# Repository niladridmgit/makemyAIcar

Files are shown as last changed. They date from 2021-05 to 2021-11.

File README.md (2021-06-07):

# makemyAIcar V2

## Below components used:
1. <del>Raspberry Pi 4 (2GB)</del> due to performance issue decided to go with **Jetson nano 4GB - B01**
2. <del>Raspberry Pi 4 Aluminum Heat Sink Case with Double Fans  [LINK](https://www.amazon.in/REES52-Raspberry-Armor-Aluminium-Heatsink/dp/B07X5XXKTZ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)</del> this is not compatible with jetson nano so added **4 Sqcm 5v colling fan**
3. <del>32gb SanDisk Extreme</del> upgraded to **USB SSD 256 gb** 
5. Raspberry Pi Camera V2 and IMX219-77 8MP Camera with 77° FOV
6. Car Chassis Transparent 4Wd  [LINK](https://www.amazon.in/gp/product/B01MT9Z9QB/ref=ppx_yo_dt_b_asin_title_o01_s00?ie=UTF8&psc=1) 
7. <del>8Ybj-48 Dc 5V 4 Phase 5 Wire Stepper Motor With Uln2003 Driver  [LINK](https://www.amazon.in/gp/product/B072T8QT62/ref=ppx_yo_dt_b_asin_title_o09_s00?ie=UTF8&psc=1)</del>
8. hc sr04 ultrasonic sensor
9. Mi Pocket Power Bank Pro 10000mAh 
10. Arduino Uno
11. DC motor arduino l293d shield
12. pca9685 servo driver
13. Expansion shield for Arduino Nano  [LINK](https://www.amazon.in/Robodo-Electronics-AR28-Expansion-Arduino/dp/B0787JNN4S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)
14. sg90 servo
15. 3d Printed parts
16. <del>tp-link dual band Wireless adapter [LINK](https://www.amazon.in/TP-Link-Archer-T2U-Wireless-Adapter/dp/B00K11UIV4)</del>

Raspberry pi 4 (2gb) has more power full and newer cpu (Broadcom BCM2711 quad-core 64-bit ARM Cortex-A72 CPU @ 1.5 GHz) compare to Jetson nano (quad-core ARM Cortex-A57 64-bit @ 1.42 GHz) but Jetson nano has power full gpu **NVIDIA Maxwell architecture with 128 NVIDIA CUDA® cores** good enough to process object detection at 30fps
for more details about Jetson Nano 4gb see here [LINK](https://developer.nvidia.com/embedded/jetson-nano-developer-kit)

We need TensorRT-accelerated deep learning networks for image recognition, object detection with localization (i.e. bounding boxes), and semantic segmentation. This inferencing library is intended to be run on the Jetson, and includes support for both C++ and Python. Various pre-trained DNN models are automatically downloaded to get you up and running quickly. 

follow the guideline mention below link to install required packages

**https://github.com/dusty-nv/jetson-inference/blob/master/docs/building-repo-2.md**

Prerequisite:

## **Install OpenCV 4.5.2** 

**https://qengineering.eu/install-opencv-4.5-on-jetson-nano.html**

### Check for updates
```
$ sudo apt-get update
$ sudo apt-get upgrade
```
### Install nano
```
$ sudo apt-get install nano
```
### Install dphys-swapfile
```
$ sudo apt-get install dphys-swapfile
```
### Give the required memory size
```
$ sudo nano /etc/dphys-swapfile
```
### Reboot 
```
$ sudo reboot.
```

### Reveal the CUDA location
```
$ sudo sh -c "echo '/usr/local/cuda/lib64' >> /etc/ld.so.conf.d/nvidia-tegra.conf"
$ sudo ldconfig
```
### Third-party libraries
```
$ sudo apt-get install build-essential cmake git unzip pkg-config
$ sudo apt-get install libjpeg-dev libpng-dev libtiff-dev
$ sudo apt-get install libavcodec-dev libavformat-dev libswscale-dev
$ sudo apt-get install libgtk2.0-dev libcanberra-gtk*
$ sudo apt-get install python3-dev python3-numpy python3-pip
$ sudo apt-get install libxvidcore-dev libx264-dev libgtk-3-dev
$ sudo apt-get install libtbb2 libtbb-dev libdc1394-22-dev
$ sudo apt-get install libv4l-dev v4l-utils
$ sudo apt-get install libgstreamer1.0-dev libgstreamer-plugins-base1.0-dev
$ sudo apt-get install libavresample-dev libvorbis-dev libxine2-dev
$ sudo apt-get install libfaac-dev libmp3lame-dev libtheora-dev
$ sudo apt-get install libopencore-amrnb-dev libopencore-amrwb-dev
$ sudo apt-get install libopenblas-dev libatlas-base-dev libblas-dev
$ sudo apt-get install liblapack-dev libeigen3-dev gfortran
$ sudo apt-get install libhdf5-dev protobuf-compiler
$ sudo apt-get install libprotobuf-dev libgoogle-glog-dev libgflags-dev
```

### Download the latest version
```
$ cd ~
$ wget -O opencv.zip https://github.com/opencv/opencv/archive/4.5.2.zip
$ wget -O opencv_contrib.zip https://github.com/opencv/opencv_contrib/archive/4.5.2.zip
```
### Unpack
```
$ unzip opencv.zip
$ unzip opencv_contrib.zip
```
### Administration to make live easier later on
```
$ mv opencv-4.5.2 opencv
$ mv opencv_contrib-4.5.2 opencv_contrib
```
### Clean up the zip files
```
$ rm opencv.zip
$ rm opencv_contrib.zip
$ cd ~/opencv
$ mkdir build
$ cd build

$ cmake -D CMAKE_BUILD_TYPE=RELEASE \
-D CMAKE_INSTALL_PREFIX=/usr \
-D OPENCV_EXTRA_MODULES_PATH=~/opencv_contrib/modules \
-D EIGEN_INCLUDE_PATH=/usr/include/eigen3 \
-D WITH_OPENCL=OFF \
-D WITH_CUDA=ON \
-D CUDA_ARCH_BIN=5.3 \
-D CUDA_ARCH_PTX="" \
-D WITH_CUDNN=ON \
-D WITH_CUBLAS=ON \
-D ENABLE_FAST_MATH=ON \
-D CUDA_FAST_MATH=ON \
-D OPENCV_DNN_CUDA=ON \
-D ENABLE_NEON=ON \
-D WITH_QT=OFF \
-D WITH_OPENMP=ON \
-D WITH_OPENGL=ON \
-D BUILD_TIFF=ON \
-D WITH_FFMPEG=ON \
-D WITH_GSTREAMER=ON \
-D WITH_TBB=ON \
-D BUILD_TBB=ON \
-D BUILD_TESTS=OFF \
-D WITH_EIGEN=ON \
-D WITH_V4L=ON \
-D WITH_LIBV4L=ON \
-D OPENCV_ENABLE_NONFREE=ON \
-D INSTALL_C_EXAMPLES=OFF \
-D INSTALL_PYTHON_EXAMPLES=OFF \
-D BUILD_opencv_python3=TRUE \
-D OPENCV_GENERATE_PKGCONFIG=ON \
-D BUILD_EXAMPLES=OFF ..

$ make -j4
$ sudo rm -r /usr/include/opencv4/opencv2
$ sudo make install
$ sudo ldconfig
```
### Cleaning (frees 300 MB)
```
$ make clean
$ sudo apt-get update
```
### Remove the dphys-swapfile now
```
$ sudo /etc/init.d/dphys-swapfile stop
$ sudo apt-get remove --purge dphys-swapfile
```
### Save an additional 275 MB
```
$ sudo rm -rf ~/opencv
$ sudo rm -rf ~/opencv_contrib
$ sudo -H pip install -U jetson-stats
$ sudo reboot
```
### Start the app with the simple command
```
$ jtop
```
## **Install GStreamer**

https://gstreamer.freedesktop.org/download/

MinGW 64-bit -> 1.18.4 runtime installer

edit environment variable and add  gstreamer bin path F:\gstreamer\1.0\mingw_x86_64\bin

in command line Terminal Execute->
```
gst-launch-1.0 -v udpsrc port=1234 caps = "application/x-rtp, media=(string)video, clock-rate=(int)90000, encoding-name=(string)H264, payload=(int)96" ! rtph264depay ! decodebin ! videoconvert ! autovideosink
```
## **OprnCV with Jetson Utility**
```
sudo nano .bashrc
add below lines
export LD_PRELOAD = /usr/lib/aarch64-linux-gnu/libgomp.so.1
export DISPLAY=:0.0
```
## **Serial Port Permission**
```
sudo usermod -a -G dialout $USER
```
## **In Progress**

## **Earlier design**
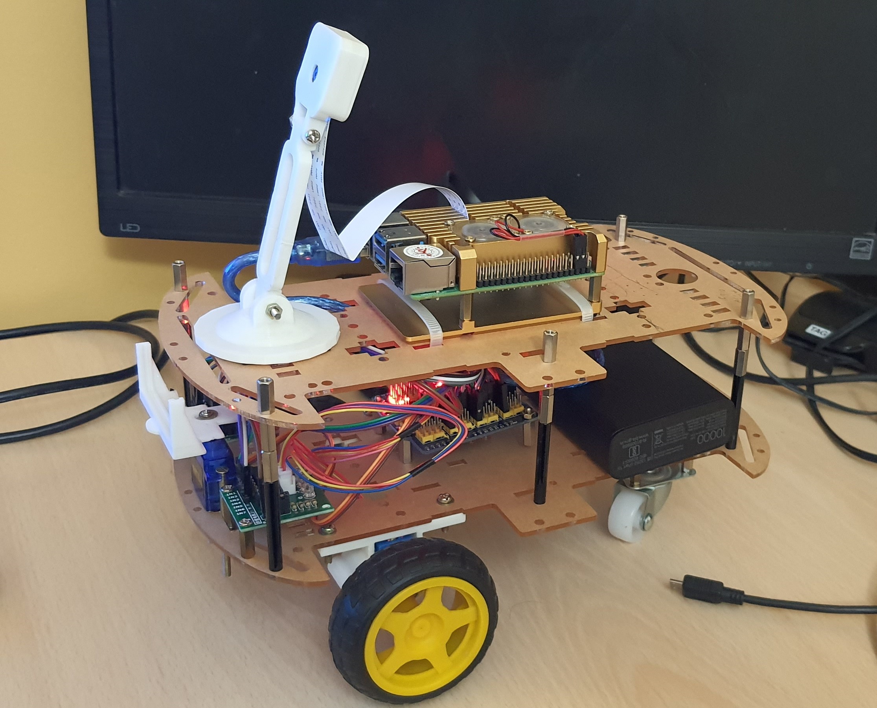
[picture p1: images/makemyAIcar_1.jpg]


## **New design**
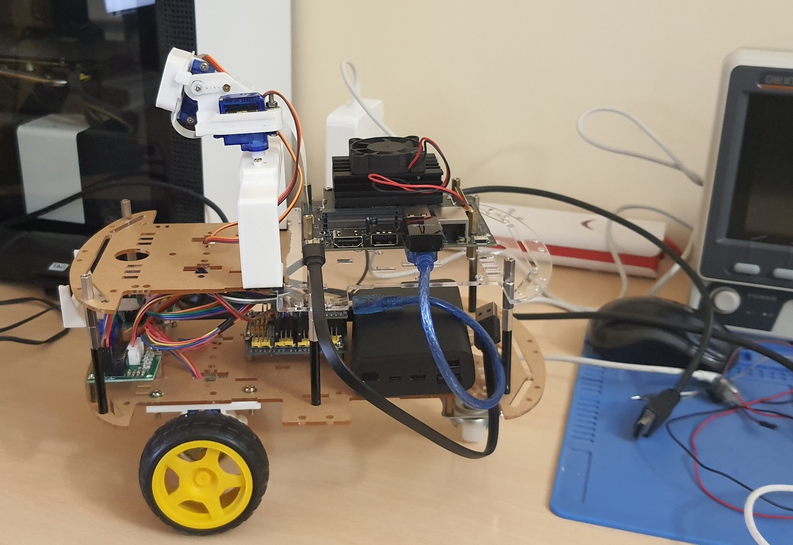
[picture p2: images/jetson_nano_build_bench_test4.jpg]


### **Assembly**
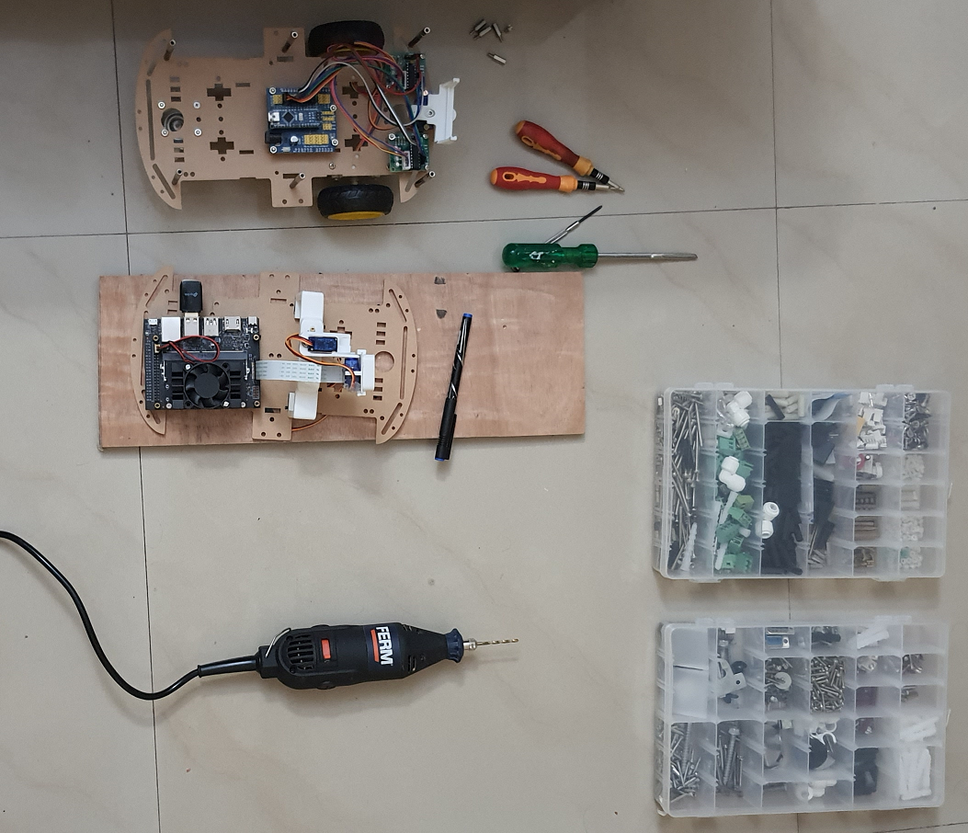
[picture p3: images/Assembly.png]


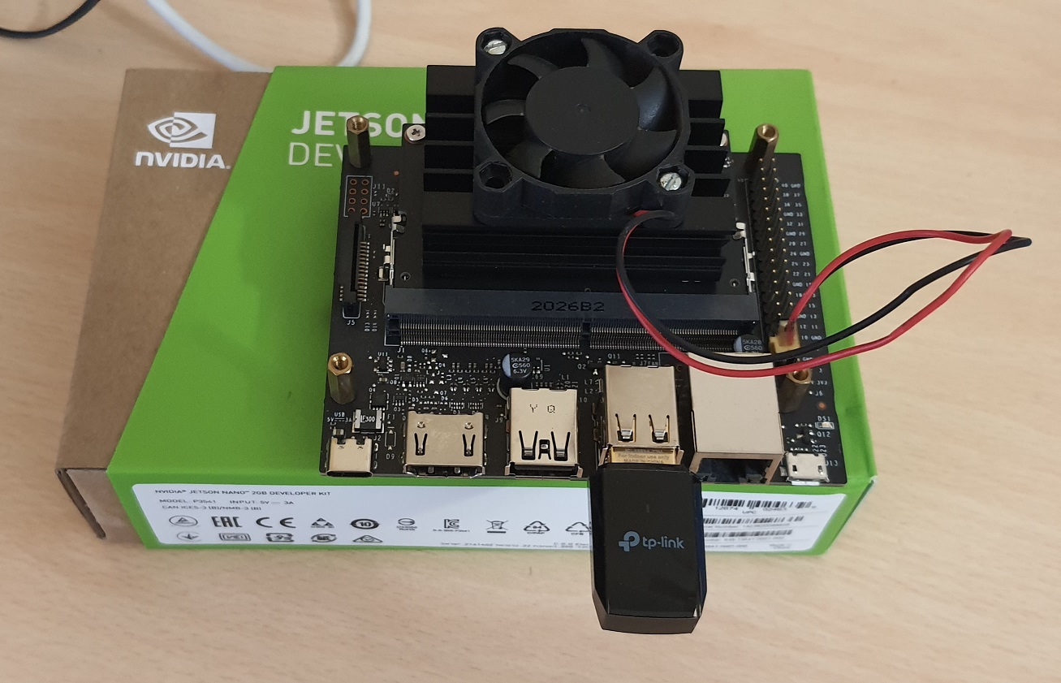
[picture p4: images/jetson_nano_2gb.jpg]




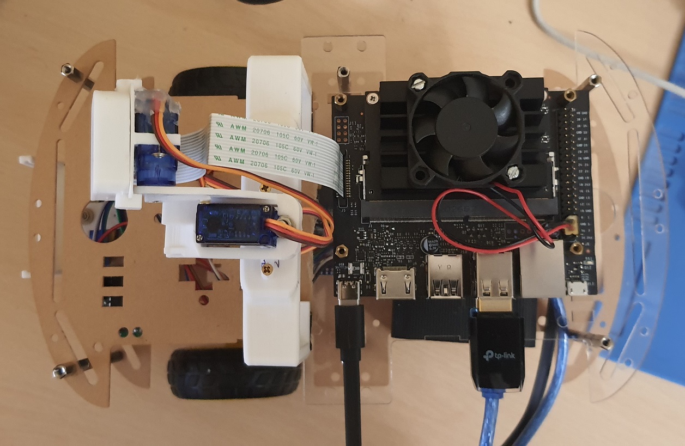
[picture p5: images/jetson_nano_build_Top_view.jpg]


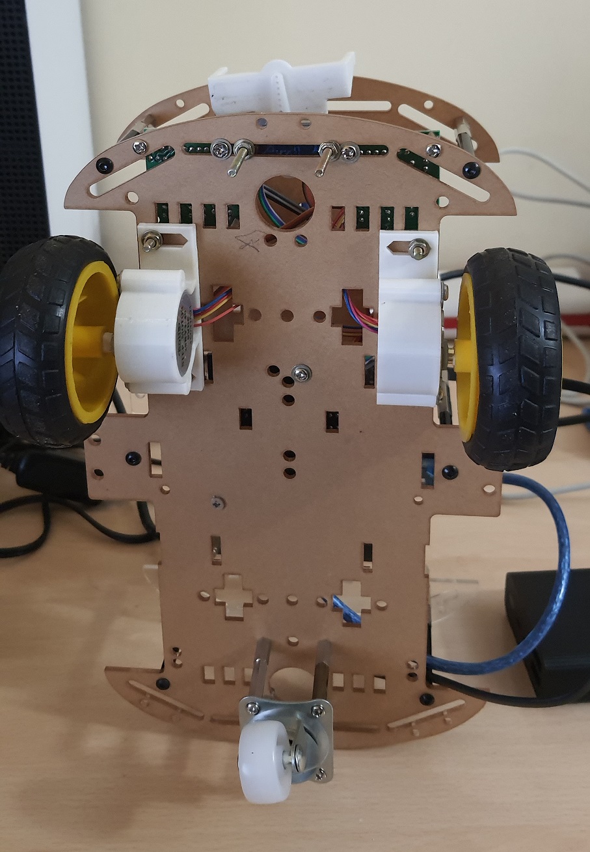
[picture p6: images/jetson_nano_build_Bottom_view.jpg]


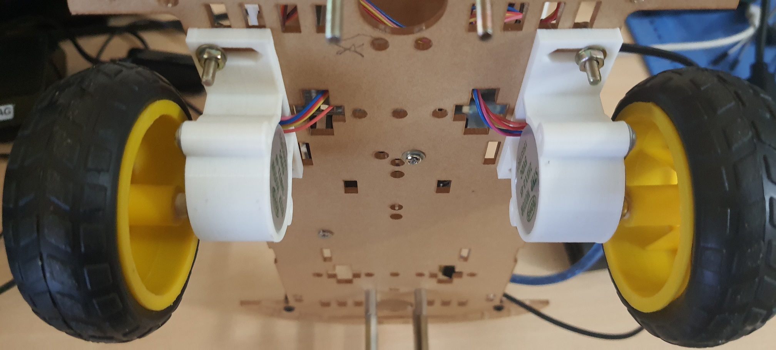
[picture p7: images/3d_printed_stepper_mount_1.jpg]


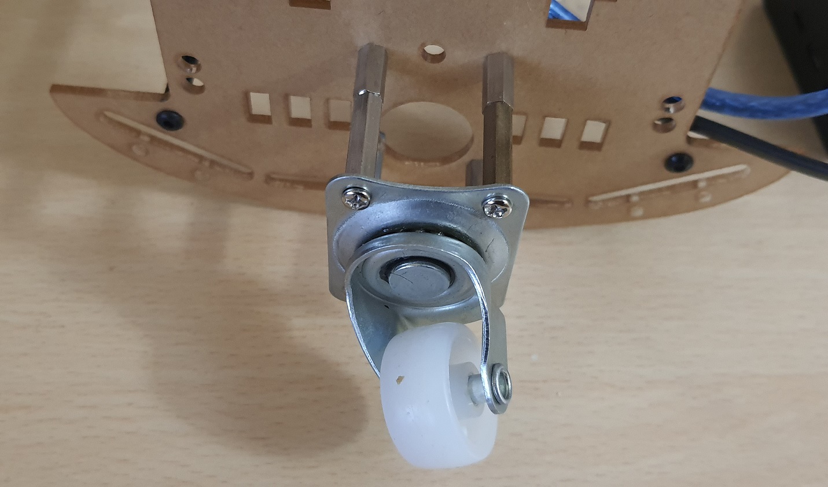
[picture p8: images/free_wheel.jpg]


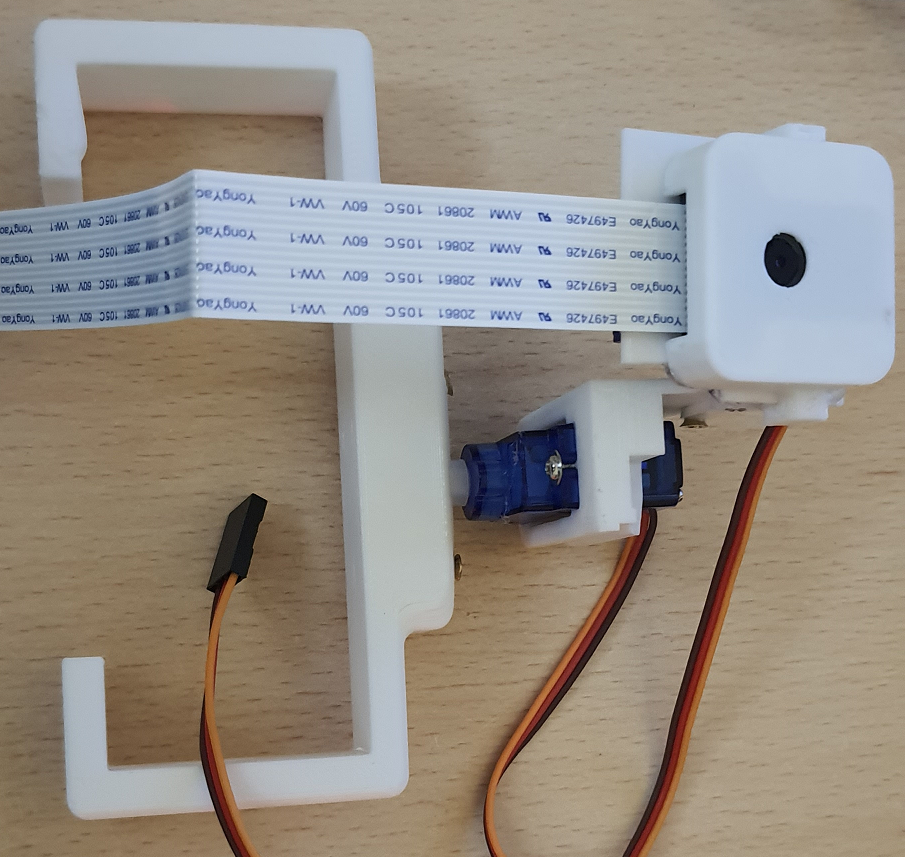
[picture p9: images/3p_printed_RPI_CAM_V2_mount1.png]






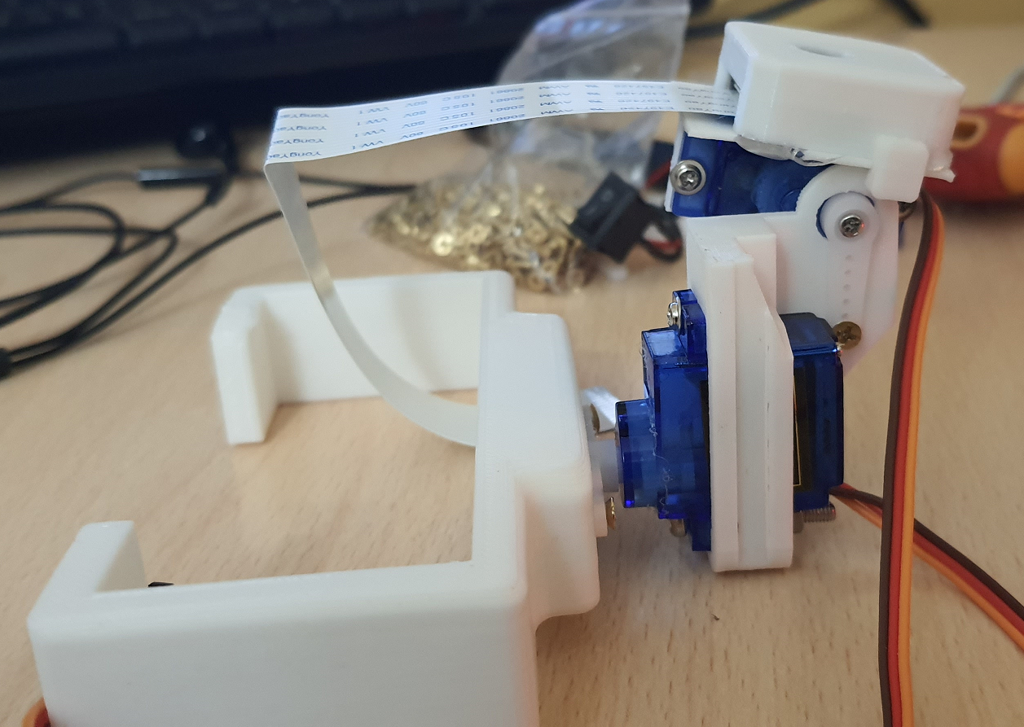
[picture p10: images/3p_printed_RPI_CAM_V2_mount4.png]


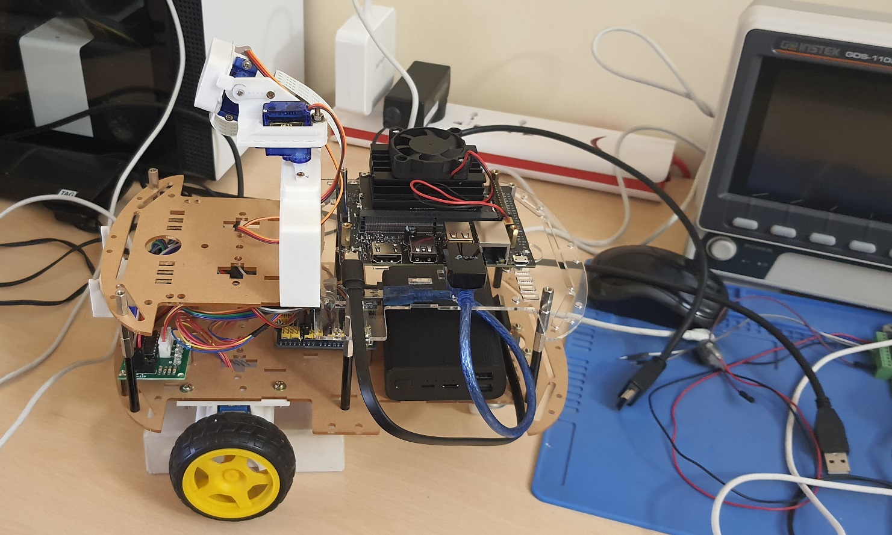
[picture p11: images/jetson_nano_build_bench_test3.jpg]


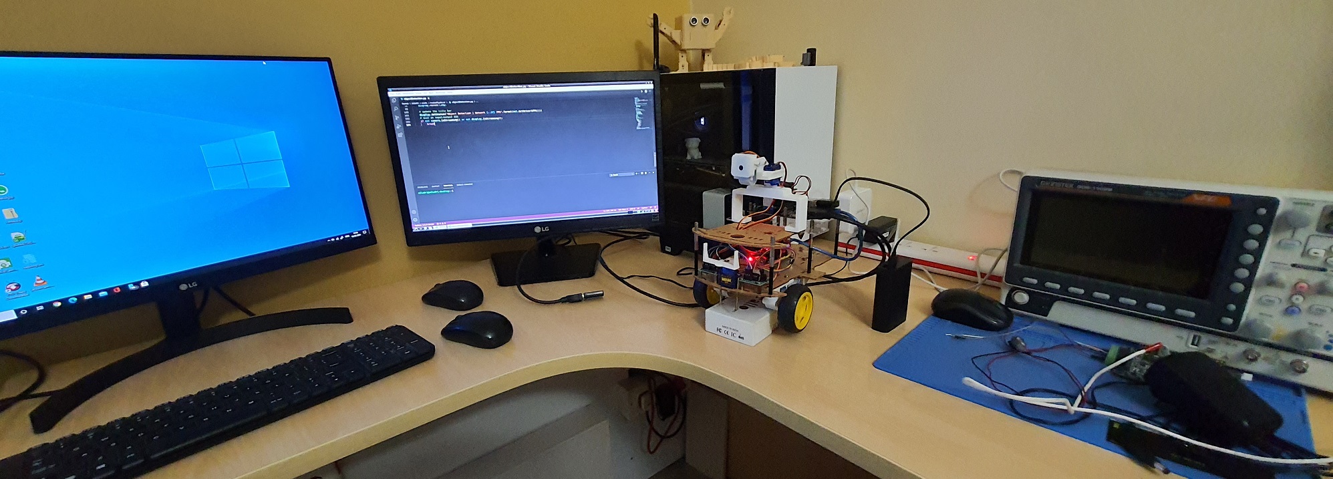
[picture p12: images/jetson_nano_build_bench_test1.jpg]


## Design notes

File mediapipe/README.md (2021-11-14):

## Jetson Nano L4T 32.5.1 aarch64
```
$ sudo apt update && \
  sudo apt install -y python3-dev protobuf-compiler python3-pip git make libssl-dev
$ sudo pip3 install pip --upgrade
$ sudo pip3 install \
numpy-1.19.4-cp36-none-manylinux2014_aarch64.whl \
mediapipe-0.8.5_cuda102-cp36-cp36m-linux_aarch64.whl
$ sudo pip3 install opencv-python dataclasses
```

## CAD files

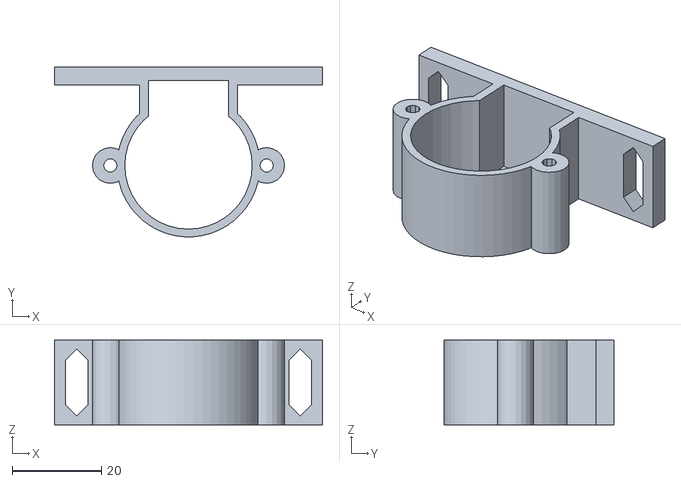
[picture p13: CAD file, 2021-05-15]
3d_models/28BYJ-48_STEPPER_HOLDER.stl
60.0 x 38.0 x 19.0

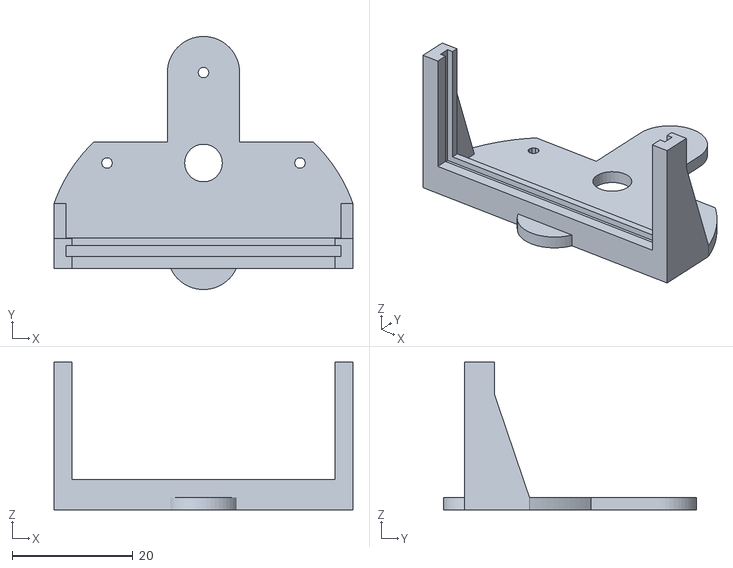
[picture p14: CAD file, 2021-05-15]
3d_models/HCSR04-MOUNT.stl
49.6 x 42.0 x 24.5

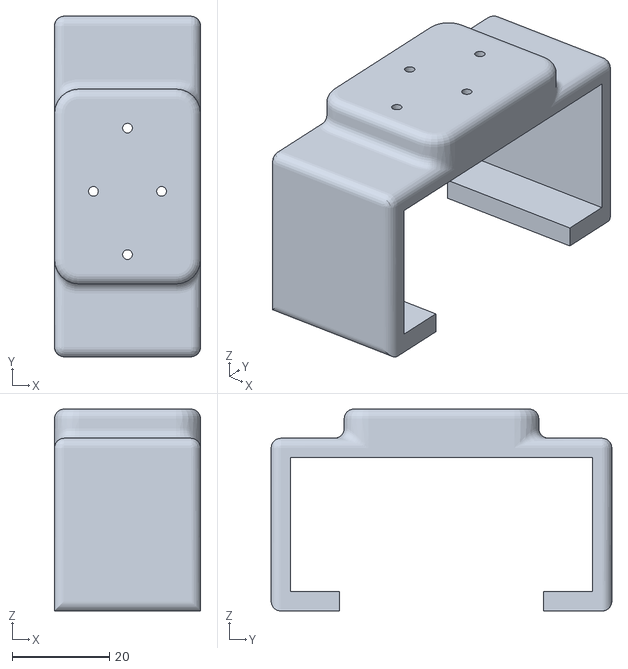
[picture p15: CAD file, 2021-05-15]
3d_models/CAMERA_MOUNT.stl
30.0 x 70.0 x 41.5

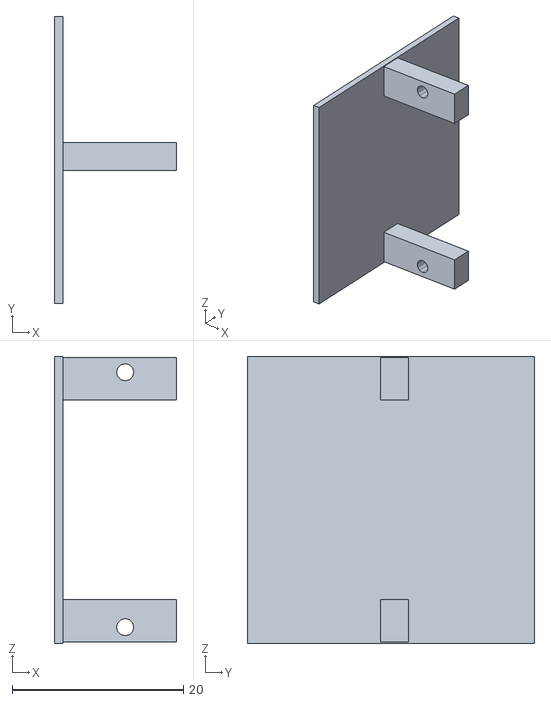
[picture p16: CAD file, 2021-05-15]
3d_models/CAMERA_BASE.stl
14.3 x 33.5 x 33.5

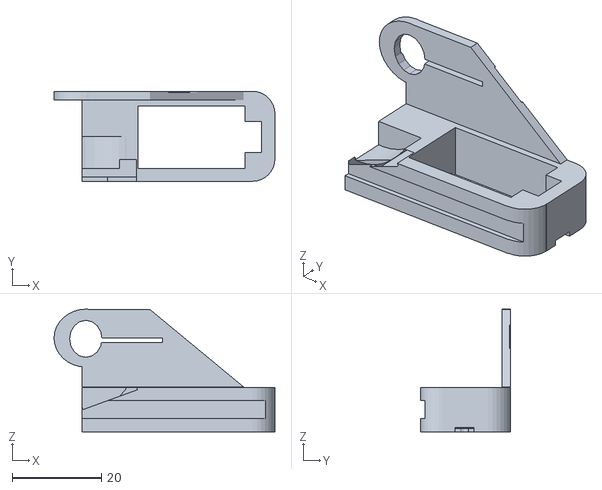
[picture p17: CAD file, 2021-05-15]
3d_models/CAMERA_ARM.stl
49.5 x 20.3 x 27.5

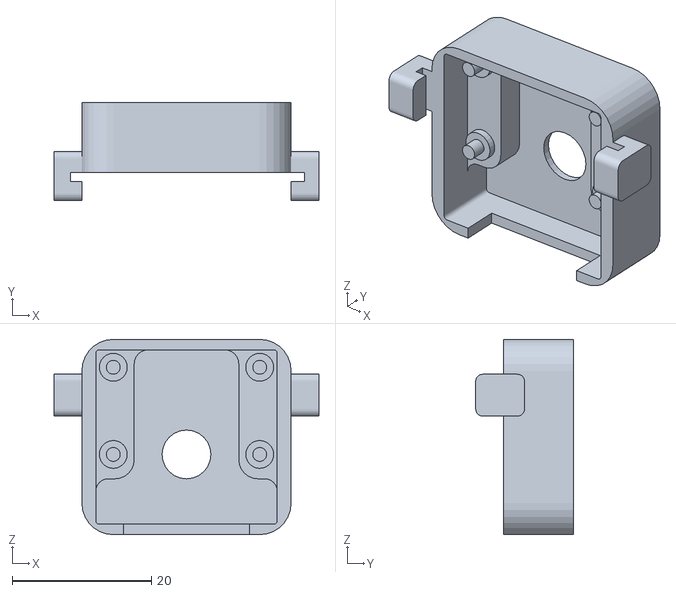
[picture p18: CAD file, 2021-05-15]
3d_models/CAMERA_COVER.stl
38.0 x 14.0 x 28.0

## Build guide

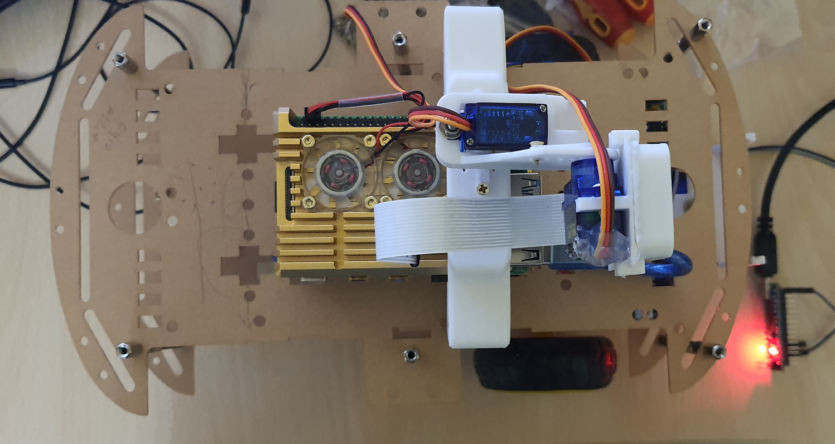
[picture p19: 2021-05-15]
images/Assembly_with_rpi_3.png

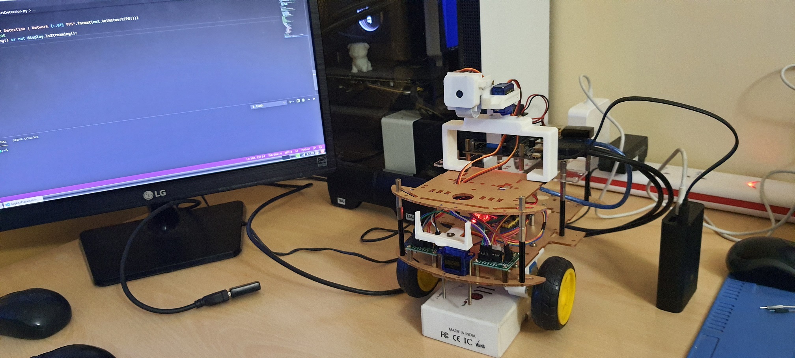
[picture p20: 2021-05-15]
images/jetson_nano_build_bench_test2.jpg

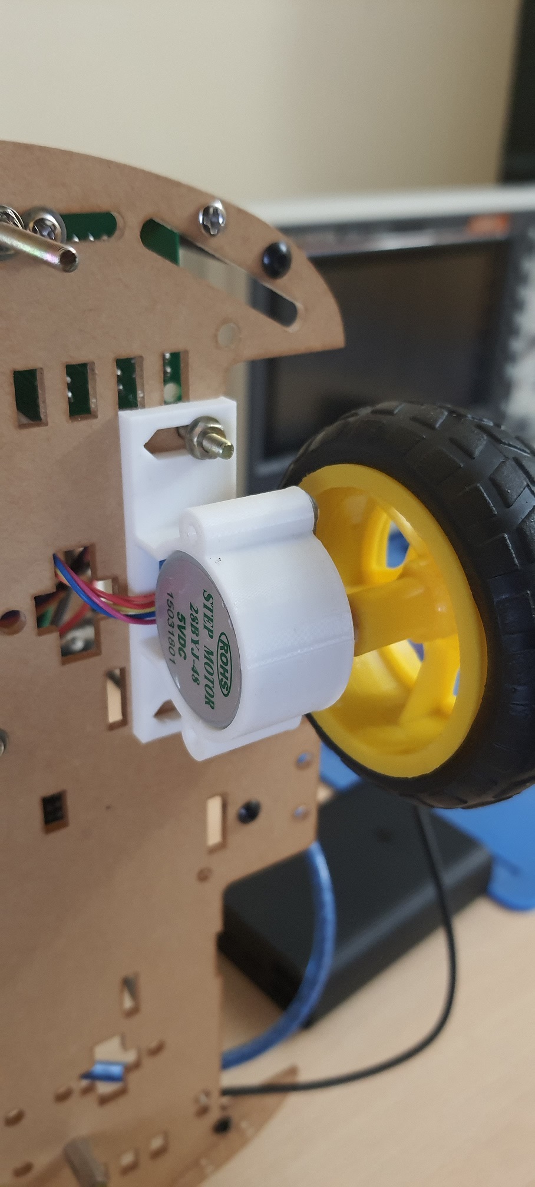
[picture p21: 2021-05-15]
images/3d_printed_stepper_mount_2.jpg

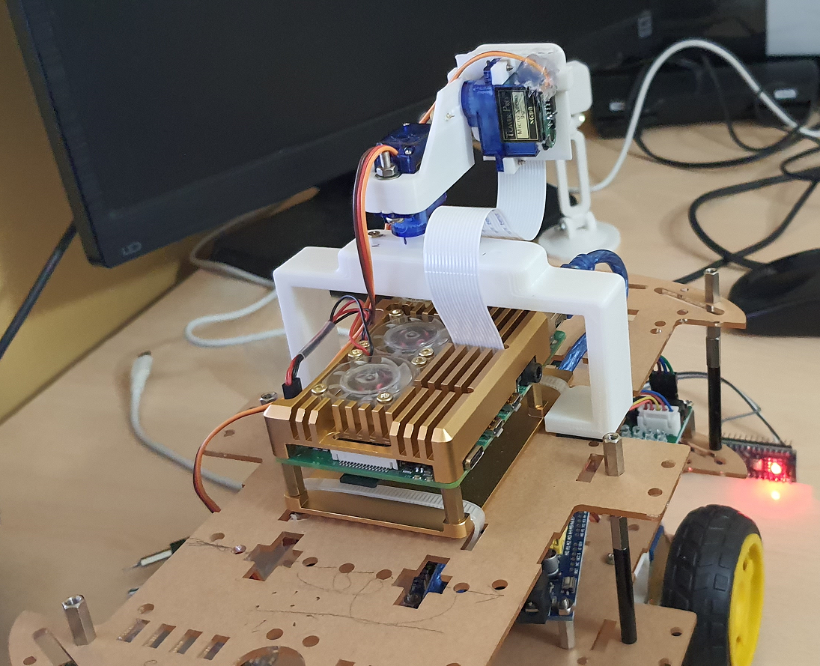
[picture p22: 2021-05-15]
images/Assembly_with_rpi_2.png

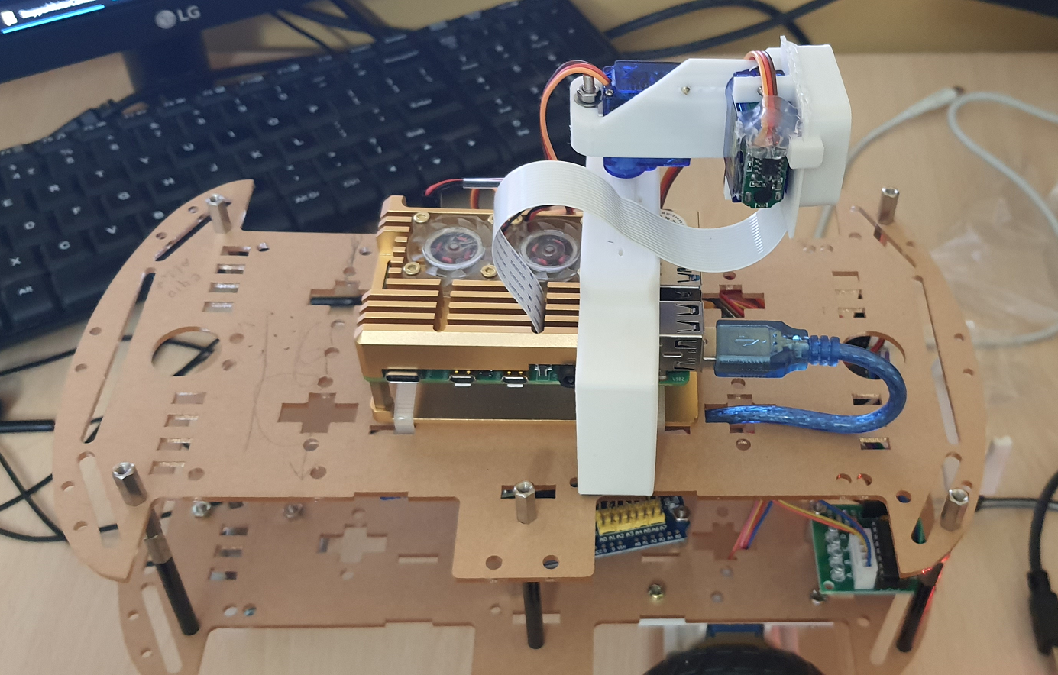
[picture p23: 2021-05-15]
images/Assembly_with_rpi_1.png

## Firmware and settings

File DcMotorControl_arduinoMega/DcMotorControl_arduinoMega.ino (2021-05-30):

#include<Servo.h>
#include <AFMotor.h>

AF_DCMotor motor1(1);
AF_DCMotor motor2(2);
AF_DCMotor motor3(3);
AF_DCMotor motor4(4);

typedef enum DIRECTION
{
  CRS_STOP = 0,
  CRS_GO,
  CRS_BACK,
  CRS_RIGHT,
  CRS_LEFT
};

#define SERVO1_pin  9
#define SERVO2_pin  10

Servo servo1_cam_yaw;
Servo servo2_cam_pitch;


unsigned int servo_pos_cam_yaw = 20;
unsigned int servo_pos_cam_pitch = 50;

bool moveClockwise = true;

unsigned int robot_dir = 0;

const byte numChars = 15;
char receivedChars[numChars];
boolean newData = false;

void clearInputBuffer();
void recvSerialcmd();
void showSerialcmd();
void dcMotorControl();
void crs_go();
void crs_stop();
void crs_back();
void crs_right();
void crs_left();

void setup() {

  // Servo Setup //
  servo1_cam_yaw.attach(SERVO1_pin);
  servo1_cam_yaw.write(90);
  servo2_cam_pitch.attach(SERVO2_pin);
  servo2_cam_pitch.write(90);
  Serial.begin(115200);
  //Serial.flush();

  motor1.setSpeed(100);
  motor1.run(RELEASE);
  motor2.setSpeed(100);
  motor2.run(RELEASE);
  motor3.setSpeed(100);
  motor3.run(RELEASE);
  motor4.setSpeed(100);
  motor4.run(RELEASE);
  
  clearInputBuffer();
  //robot_dir=CRS_GO;
  
}

void clearInputBuffer() {
   while (Serial.available() > 0) {
        Serial.read();
   }
}

void recvSerialcmd() {
  static boolean recvInProgress = false;
  static byte ndx = 0;
  char startMarker = '<';
  char endMarker = '>';
  char rc;
  
  if (Serial.available() > 0) {
    while (Serial.available() > 0 && newData == false) { // <<== NEW - get all bytes from buffer
      rc = Serial.read();

      if (recvInProgress == true) {
        if (rc != endMarker) {
          receivedChars[ndx] = rc;
          ndx++;
          if (ndx >= numChars) {
            ndx = numChars - 1;
          }
        }
        else {
          receivedChars[ndx] = '\0'; // terminate the string
          recvInProgress = false;
          ndx = 0;
          newData = true;
        }
      }

      else if (rc == startMarker) {
        recvInProgress = true;
      }
    } 
  }
}

void showSerialcmd() {
  if (newData == true) {
    Serial.print("Received: ");
    //Serial.println(receivedChars);
    if(strcmp(receivedChars, "GO") ==0)
    {
      crs_stop();
      robot_dir=CRS_GO;
    }
    else if(strcmp(receivedChars, "STOP") ==0) 
    {
      crs_stop();
      robot_dir=CRS_STOP;
    }
    else if(strcmp(receivedChars, "BACK") ==0) 
    {
      crs_stop();
      robot_dir=CRS_BACK;
    }
    else if(strcmp(receivedChars, "RIGHT") ==0) 
    {
      crs_stop();
      robot_dir=CRS_RIGHT;
    }
    else if(strcmp(receivedChars, "LEFT") ==0) 
    {
      crs_stop();
      robot_dir=CRS_LEFT; 
    }
    else if(strncmp(receivedChars, "SERVO1",6) ==0) 
    {
      String get_servo_pos = receivedChars;
      int servo_pos = get_servo_pos.indexOf(',');
      if(servo_pos)
      {
        String rx_servo_pos = get_servo_pos.substring(servo_pos+1);
        if(rx_servo_pos.length()>0)
        {
          int rx_servo_pos_int = (int)rx_servo_pos.toInt();
          Serial.println(rx_servo_pos_int);
          if(rx_servo_pos_int>=30 && rx_servo_pos_int<=160)
          {
            servo1_cam_yaw.write(rx_servo_pos_int);
          }
        }
      }
      
    }
    else if(strncmp(receivedChars, "SERVO2",6) ==0) 
    {
      String get_servo_pos = receivedChars;
      int servo_pos = get_servo_pos.indexOf(',');
      if(servo_pos)
      {
        String rx_servo_pos = get_servo_pos.substring(servo_pos+1);
        if(rx_servo_pos.length()>0)
        {
          int rx_servo_pos_int = (int)rx_servo_pos.toInt();
          Serial.println(rx_servo_pos_int);
          if(rx_servo_pos_int>=60 && rx_servo_pos_int<=140)
          {
            servo2_cam_pitch.write(rx_servo_pos_int);
          }
        }
      }
    }
    newData = false;
  }
}

void crs_go()
{

  motor1.setSpeed(240);
  motor1.run(FORWARD);
  motor2.setSpeed(240);
  motor2.run(FORWARD);
  motor3.setSpeed(240);
  motor3.run(FORWARD);
  motor4.setSpeed(240);
  motor4.run(FORWARD);
   
}

void crs_stop()
{
  motor1.setSpeed(50);
  motor1.run(RELEASE);
  motor2.setSpeed(50);
  motor2.run(RELEASE);
  motor3.setSpeed(50);
  motor3.run(RELEASE);
  motor4.setSpeed(50);
  motor4.run(RELEASE);
}

void crs_back()
{
  motor1.setSpeed(240);
  motor1.run(BACKWARD);
  motor2.setSpeed(240);
  motor2.run(BACKWARD);
  motor3.setSpeed(240);
  motor3.run(BACKWARD);
  motor4.setSpeed(240);
  motor4.run(BACKWARD);
   
}

void crs_right()
{

  motor1.setSpeed(240);
  motor1.run(BACKWARD);
  motor2.setSpeed(240);
  motor2.run(FORWARD);
  motor3.setSpeed(240);
  motor3.run(BACKWARD);
  motor4.setSpeed(240);
  motor4.run(FORWARD);
    
}
void crs_left()
{

  motor1.setSpeed(240);
  motor1.run(FORWARD);
  motor2.setSpeed(240);
  motor2.run(BACKWARD);
  motor3.setSpeed(240);
  motor3.run(FORWARD);
  motor4.setSpeed(240);
  motor4.run(BACKWARD);
    
}
void dcMotorControl()
{
  if(robot_dir==CRS_GO)
  {
    crs_go();
  }
  else if(robot_dir==CRS_STOP)
  {
    crs_stop();
  }
  else if(robot_dir==CRS_BACK)
  {
    crs_back();
  }
  else if(robot_dir==CRS_RIGHT)
  {
    crs_right();
  }
  else if(robot_dir==CRS_LEFT)
  {
    crs_left();
  }
}

void loop() {
  recvSerialcmd();
  showSerialcmd();
  dcMotorControl();
}

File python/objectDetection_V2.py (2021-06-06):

#export LD_PRELOAD=/usr/lib/aarch64-linux-gnu/libgomp.so.1
import jetson.inference
import jetson.utils
import cv2
import numpy as np
from csi_camera import CSI_Camera
from dcMotorControl import dcMotorControl
from rpiVoice import rpiVoice
from adafruit_servokit import ServoKit 
from datetime import datetime

#net = jetson.inference.detectNet("facenet-120", threshold=0.5)
net = jetson.inference.detectNet("ssd-mobilenet-v2", threshold=0.5)
display = jetson.utils.videoOutput("rtp://192.168.1.120:1234")

dc_motor = dcMotorControl()
RPI_VOICE_CMD = ["START"]
rpi_voice = rpiVoice()


DISPLAY_WIDTH=640
DISPLAY_HEIGHT=480
SENSOR_MODE_1080=2
SENSOR_MODE_720=3

pid = [0.4,0.4,0]
pError = 0

def millis(start_time):
   dt = datetime.now() - start_time
   ms = (dt.days * 24 * 60 * 60 + dt.seconds) * 1000 + dt.microseconds / 1000.0
   return ms

def show_camera():
    rpi_voice.start(RPI_VOICE_CMD)
    left_camera = CSI_Camera()
    left_camera.create_gstreamer_pipeline(
            sensor_id=0,
            sensor_mode=SENSOR_MODE_720,
            framerate=30,
            flip_method=2,
            display_height=DISPLAY_HEIGHT,
            display_width=DISPLAY_WIDTH,
    )
    left_camera.open(left_camera.gstreamer_pipeline)
    left_camera.start()
    cv2.namedWindow("img show", cv2.WINDOW_AUTOSIZE)
    if (
        not left_camera.video_capture.isOpened()
     ):
        # Cameras did not open, or no camera attached

        print("Unable to open any cameras")
        # TODO: Proper Cleanup
        SystemExit(0)
    try:
        # Start counting the number of frames read and displayed
        left_camera.start_counting_fps()
        start_time = datetime.now()
        send_voice = datetime.now()
        cam_servo = ServoKit(channels=16)
        pan_angle = 90
        pitch_angle=90
        cam_servo.servo[0].angle=pan_angle
        cam_servo.servo[1].angle=pitch_angle
        step = 1
        while cv2.getWindowProperty("img show", 0) >= 0 :
            _ ,img=left_camera.read()
            imgCuda=jetson.utils.cudaFromNumpy(img)
            detections = net.Detect(imgCuda)
            process = 0

            for d in detections:
                #print(net.GetClassDesc(d.ClassID))
                #print(d.ClassID)
                #if millis(send_voice)>5000:
                    #rpi_voice.sendText(net.GetClassDesc(d.ClassID))
                    #print(RPI_VOICE_CMD[0])
                    #send_voice = datetime.now()

                if d.ClassID==1: #47:
                    process=1
                    x1,y1,x2,y2 = int(d.Left),int(d.Top),int(d.Right),int(d.Bottom)
                    #className = net.GetClassDesc(d.ClassID)
                    #print(d.ClassID)
                    cv2.rectangle(img,(x1,y1),(x2,y2),(255,255,255),2)
                    #cv2.putText(img,str(className)+", fps:"+format(net.GetNetworkFPS(), '.2f'),(x1+5,y1+20),cv2.FONT_HERSHEY_DUPLEX,0.75,(255,0,255),2)
                    #cv2.putText(img,format(net.GetNetworkFPS(), '.2f'),(x1+5,y1+45),cv2.FONT_HERSHEY_DUPLEX,0.75,(255,0,255),2)
                    #print("Object Detection | Network {:.0f} FPS".format(net.GetNetworkFPS()))
                    w= x2-x1
                    h= y2-y1
                    area = w*h
                    cv2.putText(img,str(area),(x1+5,y1+15),cv2.FONT_HERSHEY_DUPLEX,0.75,(255,0,255),2)
                    x_c = x1 + w/2
                    y_c = y1+ h/2
                    cv2.line(img,(int(x_c),y1),(int(x_c),y2),(255,255,0),2)
                    cv2.line(img,(x1,int(y_c)),(x2,int(y_c)),(255,255,0),2)
                    cv2.circle(img,(int(x_c),int(y_c)),3,(255.255,255),2)
                    cv2.line(img,(int(x_c),int(y_c)),(int(DISPLAY_WIDTH/2),int(y_c)),(0,0,255),2)
                    cv2.line(img,(int(x_c),int(y_c)),(int(x_c),int(DISPLAY_HEIGHT/2)),(255,0,0),2)

                if millis(start_time)>50:
                    if RPI_VOICE_CMD[0] =='END':
                        dc_motor.sendCmd(1)
                        continue
                    if process==1:
                        #print(millis(start_time))
                        pan = (DISPLAY_WIDTH/2) - x_c
                        pitch = (DISPLAY_HEIGHT/2) - y_c
                        #print("pan {} pitch {}".format(pan,pitch))
                        if pan>50:
                            if (pan_angle - step) < 170:
                                if pan>50:
                                    pan_angle += step
                                    pan_angle += step
                                    pan_angle += step
                                    pan_angle += step
                                    pan_angle += step
                                pan_angle += step
                                # Camera PAN Right#
                                #cam_servo.servo[0].angle = pan_angle
                            # DC Motor Right #
                            dc_motor.sendCmd(2)
                            #print('Left')
                        elif pan<-50:
                            if (pan_angle - step) > 10:
                                if pan<-50:
                                    pan_angle -= step
                                    pan_angle -= step
                                    pan_angle -= step
                                    pan_angle -= step
                                    pan_angle -= step
                                pan_angle -= step
                                # Camera PAN Left#
                                #cam_servo.servo[0].angle=pan_angle
                            # DC Motor Left #
                            dc_motor.sendCmd(3)
                            #print('Right')
                        elif area < 200000 :
                            dc_motor.sendCmd(0)
                            #print('Go')
                        elif area > 240000 :
                            dc_motor.sendCmd(4)
                            #print('Back')
                        else:
                            dc_motor.sendCmd(1)
                            #print('Stop')
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

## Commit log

2021-05-10 StepperMotorControl_arduinoNano.ino added
2021-05-15 3d models added
    [28BYJ-48_STEPPER_HOLDER.stl, CAMERA_ARM.stl, CAMERA_BASE.stl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]
2021-05-15 Assembly.png added
2021-05-22 CAMERA_BASE.gcode added
2021-05-30 1. 4 Wheel DC Motor Control using Arduino UNO 2. RPI Voice Kit
2021-05-30 makemyAIcar - 4 wheel DC motors and RPI Voice Kit
2021-06-07 mediapipe for jetson
